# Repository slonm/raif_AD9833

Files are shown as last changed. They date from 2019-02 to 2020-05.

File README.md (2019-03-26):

Устройство читает список программ из конфигурационного файла raif.cfg, который необходимо поместить в корень файловой системы SD карты.

## Формат конфигурационного файла

Каждая строка файла, которая начинается с числового символа или двоеточия, считается описанием лечебной программы.
Все остальные строки игнорируются при чтении.
Программы нумеруются подряд по мере обнаружения их в конфигурационном файле с единицы.

Строка лечебной программы состоит из пар <частота[:длительность]>, разделенных пробелами.

Частота записывается в герцах а формате с плавающей точкой.
Опциональная длительность записывается в целых минутах в пределах 1-255 мин. Длительность по умолчанию 5 мин.
В самом начале строки может быть указана длительность по умолчанию для всех частот программы.

### Пример

```
#1 program

#Musical notes
261.63:1 293.66:2 329.63:3 349.23:4 392.00:5 440.00:6 493.88:7
:1.5 2720 2489 2170 2000 1865 1800 1600 1550 880 832 802 787 776 727 660 465 450 444 440 428 380 250 146 125 95 72 20 1.2
10000 3000 95 3
2720 2170 1865 1550 880 802 787 727 500 444 190
#5 program
2720 2170 1865 1550 880 802 787 760 727 690 660 500 465 450 444 428 190
```
строки 1, 2, 3, 8 игнорируются

строки 4, 5, 6, 7, 9 программные строки

строка 4 состоит из 7ми частот. Для каждой частоты указана своя длительность после знака :

строка 5 состоит из 28 частот. Все частоты имеют длительность 1,5 минуты

строка 6 состоит из 4х частот. Все частоты имеют длительность 5 минут

## Описание файлов
*raif_AD9833.ino* скетч Arduino

*raif_AD9833_bb.png* схема монтажная

*raif.cfg* конфигурационный файл для записи на SD карту

*sd-pin-description-2w.png* распиновка SD карты

*sd-pin-description-4w.png* распиновка mini SD карты

## Ссылки

- [Таблица частот Райфа](http://khoroshih.com/?p=8162)

- [Генератор сигналов на AD9833](https://tsibrov.blogspot.com/2018/06/ad9833.html)

- [Работа с SD картой. Подключение к микроконтроллеру](http://chipenable.ru/index.php/programming-avr/209-rabota-s-sd-kartoy-podklyuchenie-k-mikrokontrolleru-ch1.html)

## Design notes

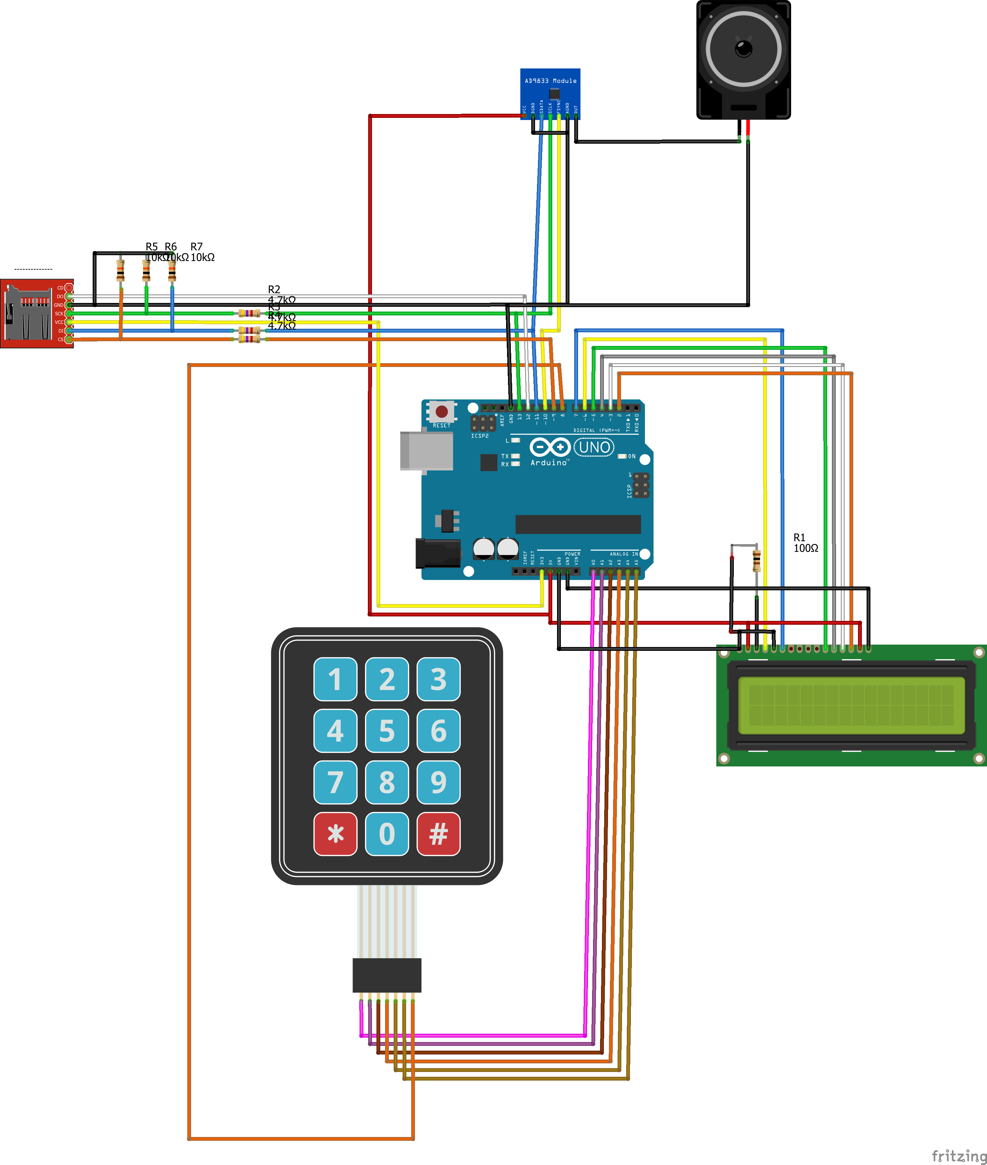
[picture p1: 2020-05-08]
raif_AD9833_bb.png

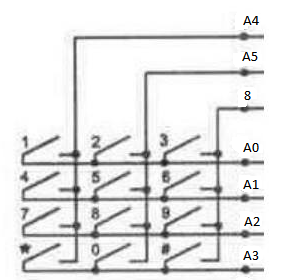
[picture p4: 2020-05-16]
keyboard.png

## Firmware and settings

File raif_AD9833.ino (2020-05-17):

#define DEBUG 0
//Назначение пинов контроллера
//LCD
const byte RS=6, E=7, DB4=5, DB5=4, DB6=3, DB7=2;
//Keypad
const byte ROWS = 4; 
const byte COLS = 3; 
const char keys[ROWS][COLS] = {
  {'1','2','3'},
  {'4','5','6'},
  {'7','8','9'},
  {'*','0','#'}
};
byte rowPins[ROWS] = {14, 15, 16, 17}; 
byte colPins[COLS] = {18, 19, 8}; 
//SPI SD card
const byte sdChipSelect = 9;
//SPI AD9833
const byte genChipSelect = SS;
//Выход "Включено"
const byte pinProgStarted = 1;
//Выход "Сигнал"
const byte pinBuzz = 0;

//https://tsibrov.blogspot.com/2018/06/ad9833.html
#include <SPI.h>
// подключаем библиотеку LiquidCrystal
#include <LiquidCrystal.h>
// библиотека клавиатуры
#include <Keypad.h>
// библиотека поддержки SD карты
#include <SD.h>

#if DEBUG
  #define SERIAL_BEGIN(a) Serial.begin(a);  while (!Serial);
  #define WRITE(a) Serial.write(a)
  #define PRINTLN(a) Serial.println(a)
  #define PRINT(a, b) Serial.print(a,b)
#else
  #define SERIAL_BEGIN(a)
  #define WRITE(a)
  #define PRINTLN(a)
  #define PRINT(a, b)
#endif
// ********** AD9833 **********
#define bMode 0x2
#define bDiv2 0x8
#define bOpbiten 0x20
#define bSleep12 0x40
#define bSleep1 0x80
#define bReset 0x100
#define bHLB 0x1000
#define bB28 0x2000
#define bCntrl_reg 0x0
#define bFreq_reg0 0x4000
#define bFreq_reg1 0x8000
#define bPhase_reg 0xC000

// инициализируем объект-экран, передаём использованные 
// для подключения контакты на Arduino в порядке:
// RS, E, DB4, DB5, DB6, DB7
LiquidCrystal lcd(RS, E, DB4, DB5, DB6, DB7);
//Инициализация объекта-клавиатуры
Keypad keypad = Keypad( makeKeymap(keys), rowPins, colPins, ROWS, COLS );

float programFrequency;
float programDelay;
uint16_t programStage;
uint16_t programStagesNumber;
bool started;

unsigned long endMillis;
unsigned long programStartMillis;
float totalMinutes;
int16_t programsNumber;
int16_t program;
float globalDefaultDelay = 3;
float programDefaultDelay = globalDefaultDelay;
bool buzz = false;

namespace sd {
  File file;
 
  void seek(uint32_t newPos) {
    if(!file.seek(newPos)) {
      file.seek(0);
      file.seek(newPos);
    }
  }
  
  void seekPrev() {
    seek(file.position() - 1);
  }

  char findNextProgram() {
    bool lineStart = file.position() == 0;
    while(file.available()) {
      char ch = file.read();
      //WRITE(ch);
      switch(ch) {
        case '\r':
        case '\n':
          lineStart = true;
          break;
        default:
          if(lineStart) {
            if(isDigit(ch) || ch == ':') {
              //PRINTLN("findNextProgram returned");
              return ch;
            }
          }
          lineStart = false;
      }
    }
    return '\0';
  }
  
  int16_t getProgramsNumber() {
    int16_t num = 0;
    char c;
    while(c = findNextProgram()) num++;
    WRITE("Programs number ");
    PRINT(num, DEC);
    PRINTLN("");
    return num;
  }
  
  float readFrequency() {
    char buff[50];
    int i=0;
    while(file.available()) {
      char ch = file.read();
      if(isDigit(ch) || ch == '.') {
        buff[i++]=ch;
      } else {
        seekPrev();
        break;
      }
    }
    buff[i]='\0';
    return atof(buff);
  }
  
  void skipSpaces(){
    while(file.available()) {
      char ch = file.read();
      if(ch != ' ' && ch != '\t') {
        seekPrev();
        return;
      }
    }
  }
  
  float readDelay() {
    if(file.available()) {
      char ch = file.read();
      if(ch == ' ' || ch == '\t') {
        skipSpaces();
        return programDefaultDelay;
      } else if (ch == '\r' || ch == '\n') {
        seekPrev();
        return programDefaultDelay;
      } else if (ch == ':') {
        char buff[50];
        int i=0;
        while(file.available()) {
          char ch = file.read();
          if(isDigit(ch) || ch == '.') {
            buff[i++]=ch;
          } else {
            seekPrev();
            break;
          }
        }
        buff[i]='\0';
        skipSpaces();
        return atof(buff);
      }
    }
    return programDefaultDelay;
  }

  float readDefaultDelay() {
    if(file.available() && file.peek() == ':') {
        char buff[50];
        int i=0;
        file.read();
        while(file.available()) {
          char ch = file.read();
          if(isDigit(ch) || ch == '.') {
            buff[i++]=ch;
          } else {
            break;
          }
        }
        buff[i]='\0';
        skipSpaces();
        return atof(buff);
    }
    return globalDefaultDelay;
  }
  
  void seekProgram(int16_t program) {
    seek(0);
    for(int i=0; i<=program; i++) {
      findNextProgram();
    }
    seekPrev();
  }
  
  void fillProgramInfo(uint16_t& stages, float& minutes) {
    stages = 0;
    minutes = 0;
    programDefaultDelay = readDefaultDelay();
    
    uint32_t progStartPos = file.position();
    do{
      char ch = file.peek();
      if(ch == '\r' || ch == '\n') {
        break;
      }
      float f = readFrequency();
      stages++;
      float d = readDelay();
      minutes += d;
      
      PRINT(stages, DEC);
      WRITE(") ");
      PRINT(f, DEC);
      WRITE(":");
      PRINT(d, DEC);
      PRINTLN();
    } while(file.available());
    PRINTLN();
    seek(progStartPos);
  }
}  

void setStarted(bool st) {
  started = st;
  endMillis = 0;
#if(!DEBUG)
  digitalWrite(pinProgStarted, st?HIGH:LOW);
#endif
}

//Запись в AD9833
void WriteAD9833(uint16_t Data){
  SPI.beginTransaction(SPISettings(SPI_CLOCK_DIV2, MSBFIRST, SPI_MODE2));
  digitalWrite(genChipSelect, LOW);
  delayMicroseconds(1);
  SPI.transfer16(Data);
  digitalWrite(genChipSelect, HIGH);
  SPI.endTransaction();
}

void printError(const char* err) {
  lcd.setCursor(0, 0);
  lcd.print(err);
  lcd.setCursor(0, 1);
  lcd.print("                 ");
}

void resetScreen() {
  lcd.setCursor(0, 0);
  lcd.print("                 ");
  lcd.setCursor(0, 1);
  lcd.print("                 ");
  lcd.setCursor(0, 0);
}

void paint(bool inputMode = false) {
  resetScreen();
  if(inputMode) {
    lcd.setCursor(0, 1);
    lcd.print("* Start  # Reset");
    lcd.setCursor(0, 0);
    lcd.print("Input prog: ");
    lcd.cursor();
  } else {
    lcd.print("Prog ");
    lcd.noCursor();
  }
  if(program >= 0) lcd.print(program + 1, DEC);
  if(started) {  
    lcd.setCursor(9, 0);
    lcd.print("Step ");
    lcd.print(programStage + 1, DEC);
    lcd.setCursor(0, 1);
    //lcd.print("F");
    lcd.print(programFrequency, 2);
    lcd.print("Hz ");
    //lcd.setCursor(12, 1);
    //lcd.print("T");
    lcd.print(programDelay, 1);
    lcd.print("m");
  }
}

void paintScreen1() {
  resetScreen();
  lcd.print("Step ");
  lcd.print(programStage + 1, DEC);
  lcd.print("/");
  lcd.print(programStagesNumber);
  lcd.setCursor(0, 1);
  lcd.print("Time ");
  lcd.print(float(millis() - programStartMillis) / 60000, 1);
  lcd.print("m/");
  lcd.print(totalMinutes, 1);
  lcd.print("m");
}

void repaint() {
  static uint32_t lastRepaintTime = millis();
  static bool lastScreen = false;
  if(millis() - lastRepaintTime > 3000) {
    if(lastScreen) {
      paint();
    } else {
      paintScreen1();
    }
    lastScreen = !lastScreen;
    lastRepaintTime = millis();
  }
}

// Установить частоту
void setFrequency(float val) {
  WRITE("Set frequency: ");
  PRINT(val, DEC);
  PRINTLN();
  programFrequency = val;
  
  WriteAD9833(bCntrl_reg | bReset | bB28);
  if(val > 0) {
    unsigned long FreqData = round(val * 10.73741824/* + 0.5*/);
    WriteAD9833(FreqData & 0x3FFF | bFreq_reg0);
    WriteAD9833((FreqData >> 14) | bFreq_reg0);
    WriteAD9833(bCntrl_reg | bB28); // Снимаем Reset
  }
}

// Установить длительность
void setDelay(float seconds) {
  programDelay = seconds;
  endMillis = millis() + seconds * 1000L * 60;
}

void startProgram() {
#if(!DEBUG)
  pinMode(pinProgStarted, OUTPUT);
  pinMode(pinBuzz, OUTPUT);
#endif
  programStagesNumber = 0;
  totalMinutes = 0;
  programStartMillis = millis();
  sd::seekProgram(program);
  sd::fillProgramInfo(programStagesNumber, totalMinutes);
  setFrequency(sd::readFrequency());
  setDelay(sd::readDelay());

  programStage = 0;
  stopBuzz();
}

void stopProgram() {
  endMillis = 0;
  program = -1;
  setStarted(false);
  setFrequency(0);
  paint(true);
  buzz = true;
}

void nextFrequency() {
  programStage++;
  if(programStage == programStagesNumber) {
    endMillis = 0;
    stopProgram();
  } else {
    setFrequency(sd::readFrequency());
    setDelay(sd::readDelay());
  }
}

void inputProgram() {
  static int16_t num1=0;
  char button = NO_KEY;
  // Здесь мы читаем клавиатуру и составляем число.
  // Цикл выполняется, пока мы не нажмем кнопку '*', и цикл прервется,
  // или, если будет нажата кнопка '#', всё начнется с начала. 
      
  button = keypad.getKey(); // Чтение кнопки
  switch(button) {
    case NO_KEY:
      return;
      //continue;
    case '#': // Если пользователь хочет сбросить набор первого числа
      num1 = 0;
      break;      
    case '*': // Если пользователь завершил ввод цифр
      break;
    default:
      num1 = num1*10 + (button -'0'); 
      break;      
  }
  WRITE("Pressed ");PRINTLN(button);
  if (num1 > programsNumber)
  {
    num1 = 0;
  }
  program = num1 - 1;
  paint(true);
  stopBuzz();
  if(button == '*' && program >= 0) {
    setStarted(true);
    num1 = 0;
  }
}

void updateBuzz() {
#if !DEBUG
  if(buzz) {
    static uint32_t lastUpdateTime = millis();
    if(millis() - lastUpdateTime > 500) {
      digitalWrite(pinBuzz, !digitalRead(pinBuzz));
      lastUpdateTime = millis();
    }
  }
#endif
}

void stopBuzz() {
#if !DEBUG
  buzz = false;
  digitalWrite(pinBuzz, LOW);
#endif
}

bool error = false;

void setup() {
  SERIAL_BEGIN(9600);
  // Инициализация синтезатора частоты
  SPI.begin();
  // Инициализация индикатора
  // устанавливаем размер (количество столбцов и строк) экрана
  lcd.begin(16, 2);
  printError("   Loading...    ");
  if (!SD.begin(sdChipSelect)) {
    printError(" SD Card failed  ");
    error = true;
    return;
  }
  sd::file = SD.open("/raif.cfg", FILE_READ );
  if (!sd::file) {
    printError("File read failed ");
    error = true;
    return;
  }
  programsNumber = sd::getProgramsNumber();
  if (programsNumber == 0) {
    printError("Read config error");
    error = true;
    return;
  }
  stopProgram();
}

void loop() {
  if(error) return;
  if(started) {
    if(endMillis == 0) {
      startProgram();
    } else if (millis() >= endMillis) {
      nextFrequency();
    }
    repaint();
    if(keypad.getKey() == '#') {
      stopProgram();
      stopBuzz();
    }
  } else {
    updateBuzz();
    inputProgram();
  }
}

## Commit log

2019-02-23 circuit fix
    [raif_AD9833.fzz]
2019-03-26 Memory optimization. Fractionan delays. Program end pinout indicator
    [raif.cfg]
2020-05-05 circuite fix
    [raif_AD9833.fzz]
2020-05-07 revert program odd changes and added keyboard pinout
    [raif_AD9833.ino]
2020-05-08 fix circuit
    [raif_AD9833.fzz]
2020-05-16 Fix keyboard pinout. Fix SD seek issue. Added Raif frequencies config
    [raif.cfg, raif_test.cfg]
